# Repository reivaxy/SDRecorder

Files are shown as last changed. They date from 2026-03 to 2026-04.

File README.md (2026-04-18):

# SDRecorder

*About 90% of the code and this README was written by Claude Haiku 4.5 through GitHub Copilot in VSC, with minimal editing.*

A compact ESP32-based audio recording device with SD card storage, WiFi web interface, and power-efficient operation for portable recording applications.

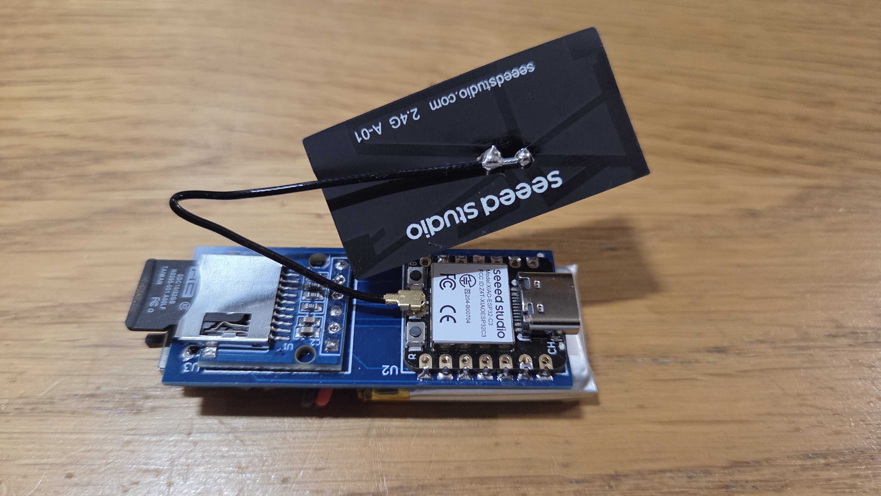
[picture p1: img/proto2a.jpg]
 
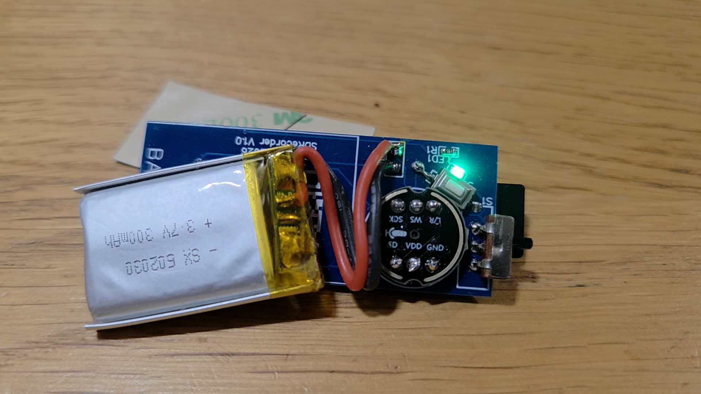
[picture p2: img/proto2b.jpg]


Here is version 2 with its case:

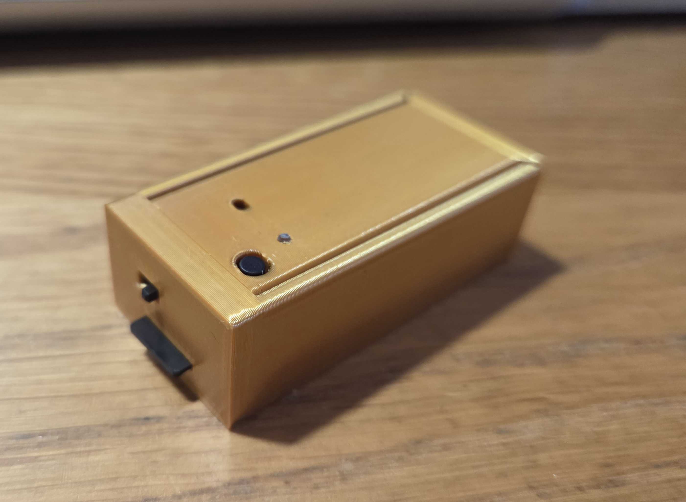
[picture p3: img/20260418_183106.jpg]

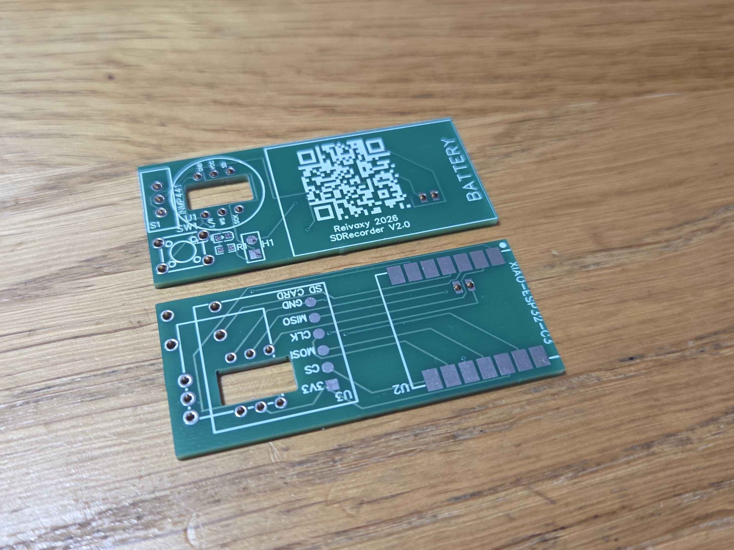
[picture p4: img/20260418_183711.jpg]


Check this recorded sample:

[rec004.wav](https://github.com/user-attachments/files/26235473/rec004.wav)

## Overview

SDRecorder is a battery-powered audio recorder that captures WAV files to an SD card. The device features a simple push-button interface for recording control, an LED status indicator, and a web-based interface for settings management and file access. The design prioritizes low power consumption through intelligent sleep modes.

## Features

- **Audio Recording**: Captures audio to SD card in WAV format
- **Automatic File Rotation**: Creates new recording files at configurable intervals to optimize storage and prevent extremely large files
- **Web-Based Interface**: Access settings, view recordings, and manage files through a WiFi access point
- **Power Efficiency**: ESP32 enters light sleep mode when idle to extend battery life
- **Simple Controls**: One push button for all operations
- **Status Indicator**: LED provides visual feedback for device status
- **File Management**: Download and delete recordings directly from the web interface
- **Flexible Settings**: Configure recording intervals, WiFi credentials, sleep timing, and more

## Push Button Usage

The single push button provides three levels of interaction:

### Quick Press (< 2 seconds)
- **First press**: Start recording
- **Second press**: Stop recording
- The device immediately begins capturing audio to the SD card when recording starts

### Long Press (2+ seconds)
- **Hold for 2 seconds but less than 6**: Start the WiFi access point
- Once activated, the device creates a WiFi network you can connect to
- Default SSID and password can be configured via the web interface at http://192.168.1.4

### Very long press (6+ seconds)
- reset the ESP32

### Power Management
- When not in use, the device automatically enters light sleep mode after a configurable delay
- Pressing the button wakes the device from sleep
- This design significantly reduces battery consumption during idle periods

## LED Status Indicators

- **Slow Flash** (every 2 seconds while recording): Device is recording audio
- **Quick Flash** (continuous): SD card error - either the card is absent or cannot be written to
- **Double Blink** (on startup): System ready and waiting for input
- **Triple Blink**: Wifi Access Point and web server started or stopped

## WiFi Web Interface

When the WiFi access point is active, connect to the network and navigate to `http://192.168.1.4` to access the web interface.

### Available Pages

#### Home Page (`/`)
Main dashboard for recording control and quick status overview
- Display current recording status
- Start/stop recording controls
- Quick access to settings and file management

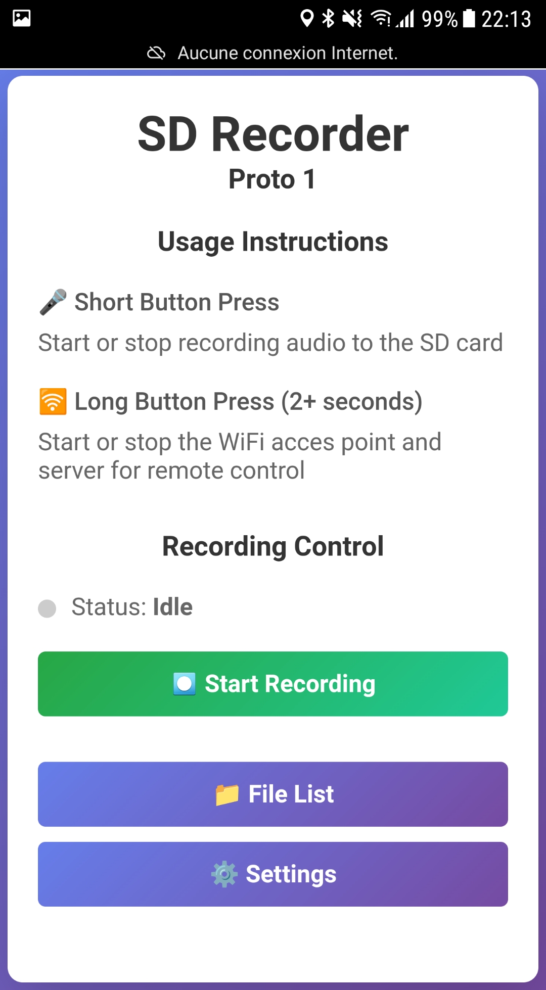
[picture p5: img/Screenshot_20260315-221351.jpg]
Home Page


After pressing the "Start Recording" button:

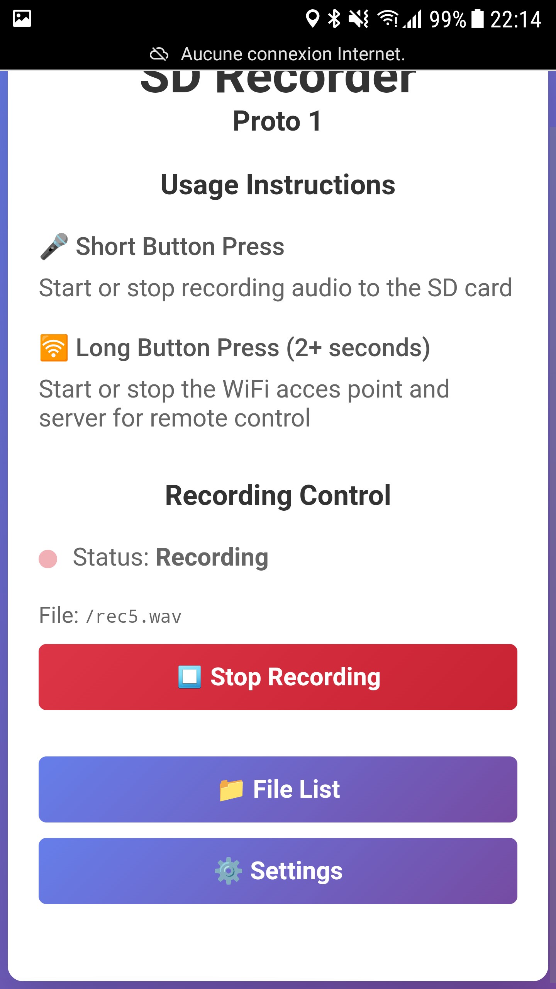
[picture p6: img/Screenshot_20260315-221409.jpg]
While recording


#### Settings Page (`/settings`)
Configure device behavior and preferences:
- **File Split Interval**: Set how many seconds of recording before a new file is created
- **WiFi Credentials**: Configure the AP SSID and password
- **Sleep Timer**: Adjust the delay before the device enters sleep mode
- **Server Auto-Start**: Enable/disable WiFi server startup after device restart
- Save and apply changes to persistent storage

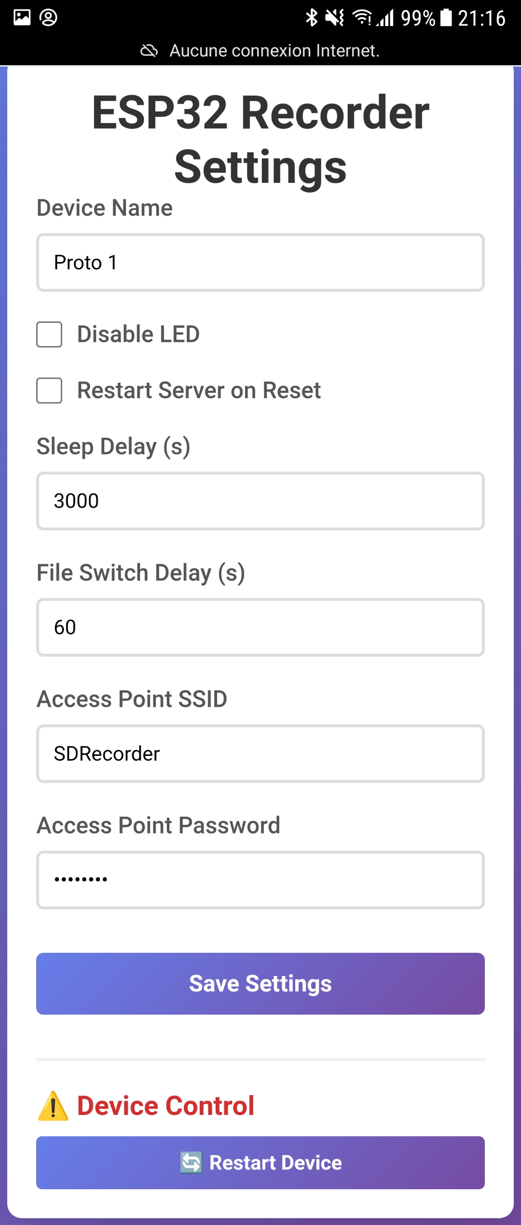
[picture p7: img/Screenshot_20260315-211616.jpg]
Settings Page


#### Files Page (`/files`)
Manage recorded audio files:
- View list of all recordings on the SD card with file sizes and date
- Download files directly to your mobile phone or computer
- Delete individual files or manage storage space

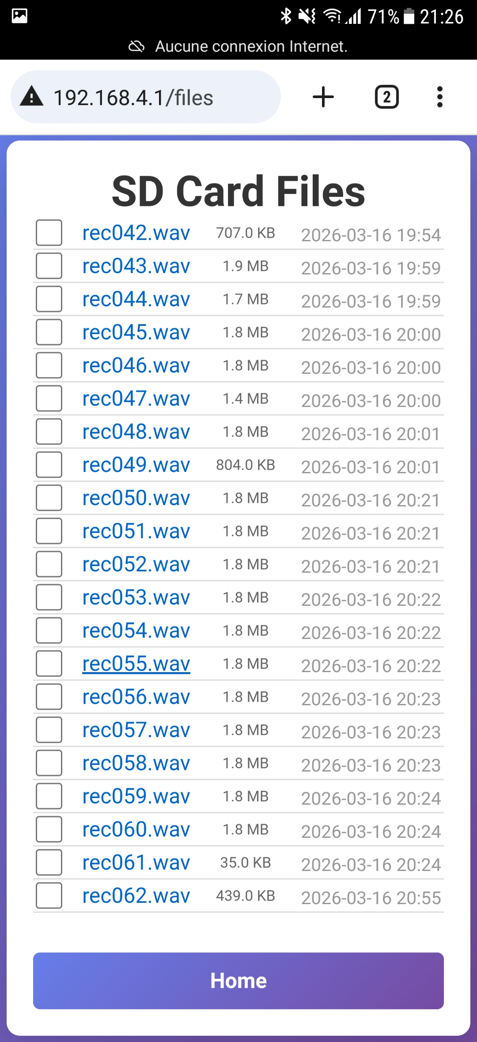
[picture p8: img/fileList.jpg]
Files Page


### API Endpoints (for advanced users)

- `GET /apis/settings` - Retrieve current settings in JSON format
- `POST /apis/settings` - Update settings
- `POST /apis/recording/start` - Start recording
- `POST /apis/recording/stop` - Stop recording
- `GET /apis/recording/status` - Get current recording status
- `POST /apis/files/delete` - Delete files
- `POST /apis/system/restart` - Restart the device
- `POST /apis/system/time` - Set the device time (accepts timestamp in JSON body)
- `GET /apis/system/time` - Get the current device time and RTC status

### Tools

A python script opens a UI allowing to select a source folder containing .wav files and stich them into one single .wav file.
This is handy in case you use the automatic file switching feature. 
Check the firmware/pc folder in this repository.

## Hardware Prototype

Here is the early breadboard prototype.



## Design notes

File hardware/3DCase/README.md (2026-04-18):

# Case

Both parts should be printed vertically.

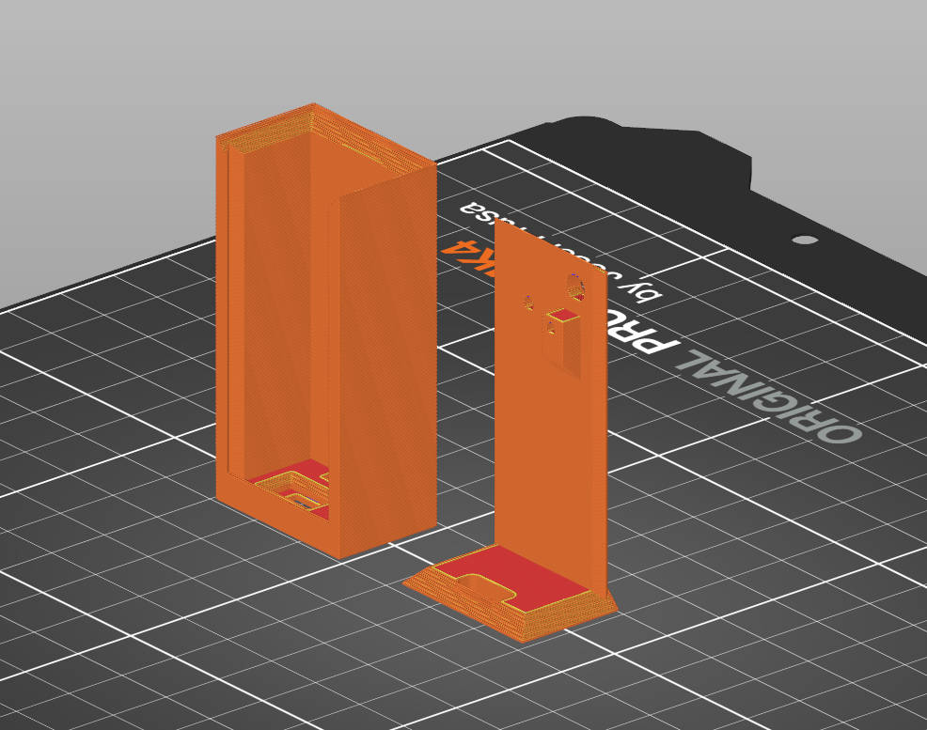
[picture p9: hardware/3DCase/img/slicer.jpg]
Slicer view
 

Assemble flat: put the bottom part on a table, then insert the USB-C in its slot while making sure the push button is going through the hole.

Then slide the top case close slowly, making sure the antenna is not squeezed at the USB extremity.

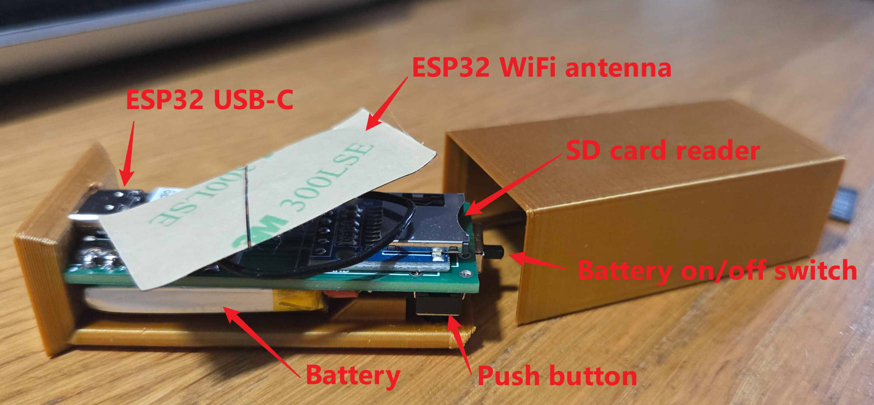
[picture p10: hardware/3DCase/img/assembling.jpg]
 

Push a little bit of optical fiber down the led hole (about 5mm should do).

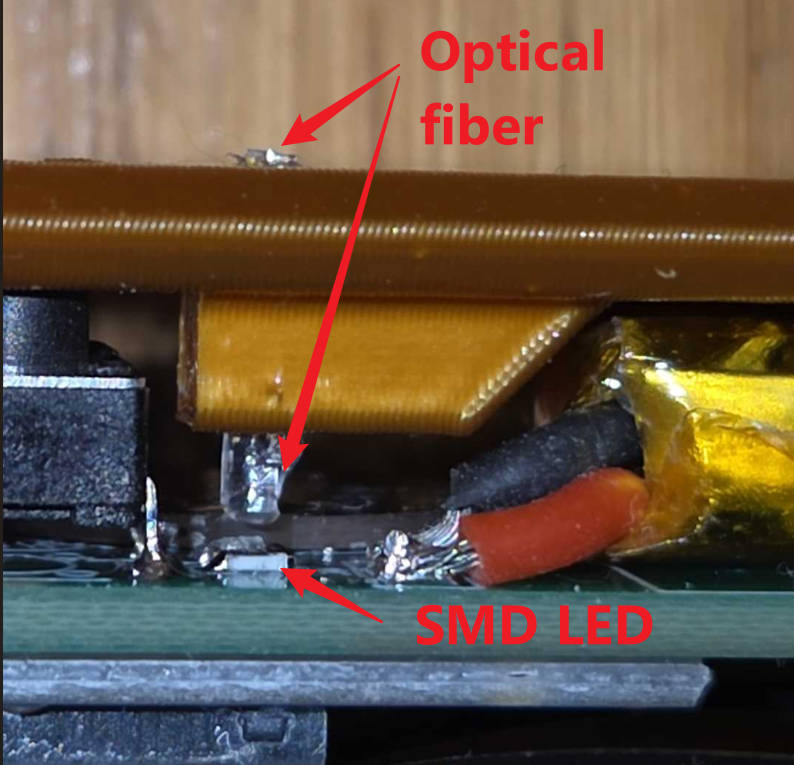
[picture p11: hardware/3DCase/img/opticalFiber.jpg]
 

And enjoy.

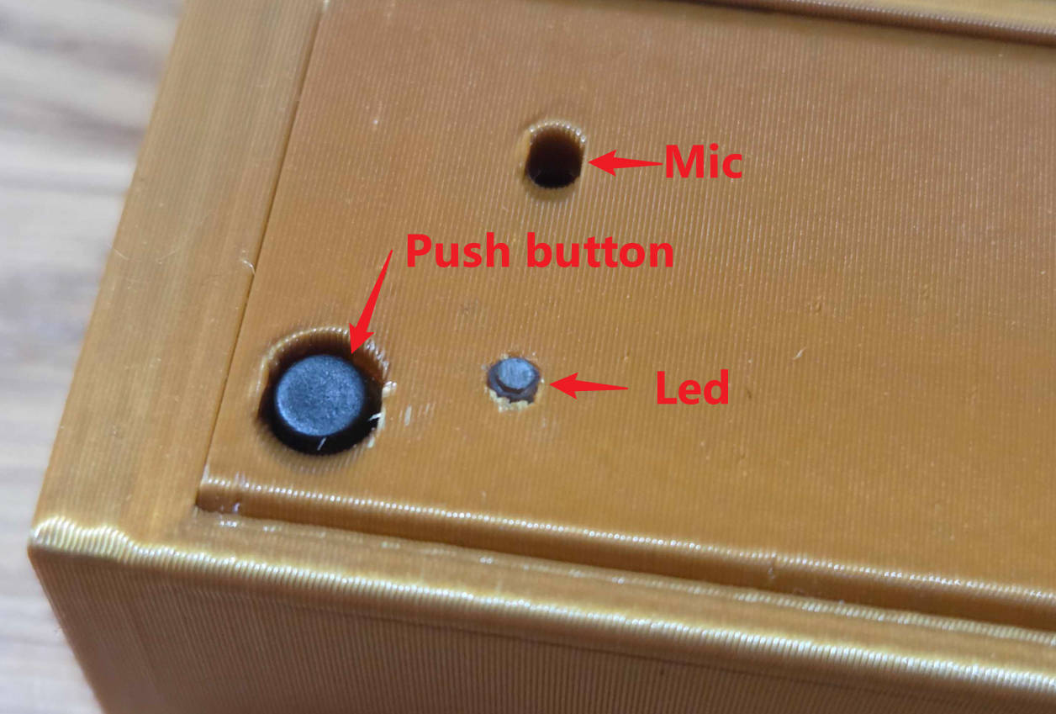
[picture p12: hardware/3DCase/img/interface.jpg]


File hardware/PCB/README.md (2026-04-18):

# PCB Manufacturing

This PCB can be easily manufactured and ordered through online PCB services such as JLCPCB, PCBWay, or similar providers.

Version 1 is a bit buggy but can work.

The push button print is not right for the push button I had in stock, and the microphone board needs to be mounted on pins. Next version should take care of this and maybe accomodate several push buttons sizes.

## How to Order

Simply upload the Gerber files to your chosen PCB manufacturer's website. The Gerber files contain all the necessary information for fabrication including traces, layers, holes, and other manufacturing specifications.

## Assembly

Three tricky parts:
- the battery pads underneath the ESP32: Put the ESP32 in place and make sure it does not move, then from the other side of the PCB heat the holes joining the pads and put solder. It worked for me. Alternatively, use solder paste and hot air, but I didn't try it yet.
- the SD board: soldered without pins, just heat the holes and put solder from the top, capilarity will do the rest.
- the microphone board: will be similar in the next pcb version, for now mount it on pins but the pins should not emerge on the other side of the pcb since the battery rests agains the pcb.

## Schematics

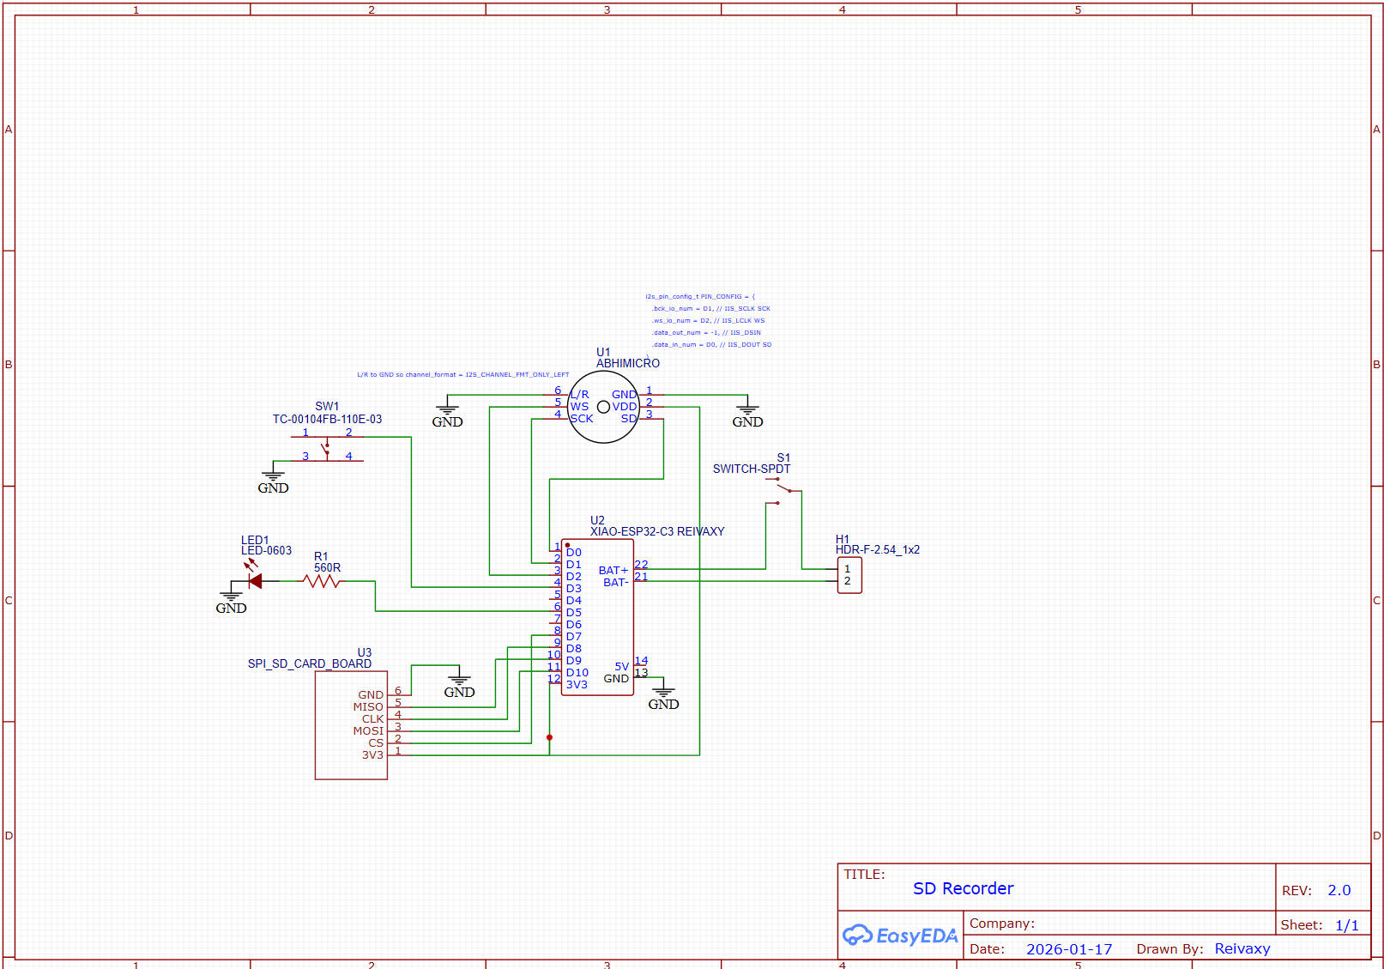
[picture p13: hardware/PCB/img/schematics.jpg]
Schematics


## PCB Views

Dimensions: 51.9 mm* 21.7 mm

Top side

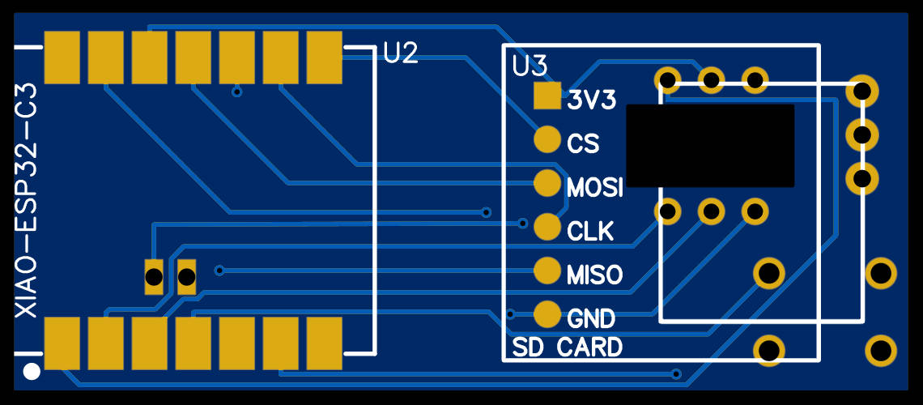
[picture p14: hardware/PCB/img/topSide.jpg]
Top Side


Bottom side

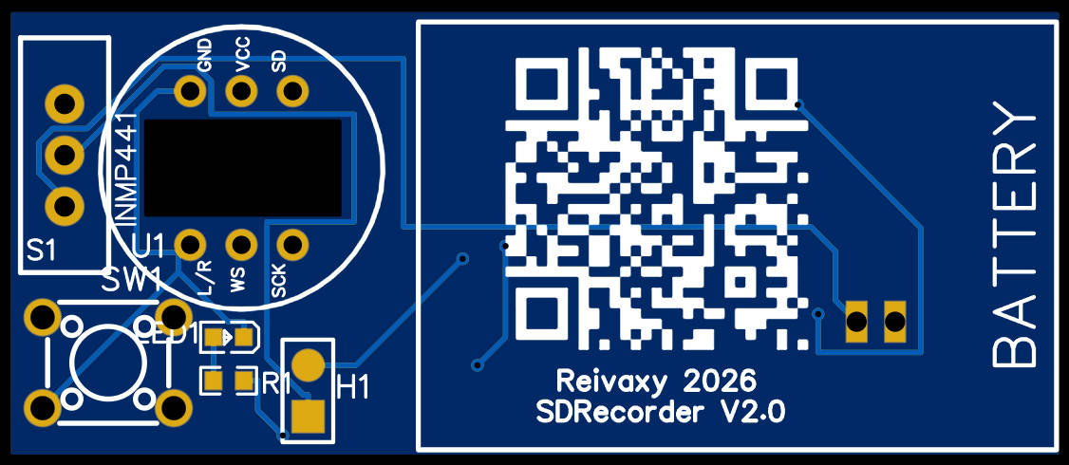
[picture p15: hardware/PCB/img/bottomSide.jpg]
Bottom Side


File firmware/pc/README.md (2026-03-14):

# .wav file merger

The mergeWav.py is a 100% AI generated unedited python script you can use to merge the .wav files produced by the SDRecorder.

When recording, the SDRecorder switches to a new file every X minutes (1 minute for now, this will be an accessible parameter through wifi soon-ish), so that not much recording is lost when the battery charge is too low to power the device.

You may need to install the PyQt6 package:

`> pip install PyQt6`

Then run the script:

`> python mergeWav.py`

This python script with a simple GUI allows to stitch them easily.

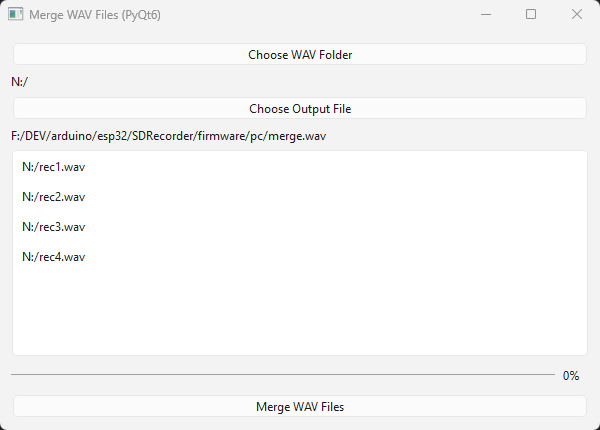
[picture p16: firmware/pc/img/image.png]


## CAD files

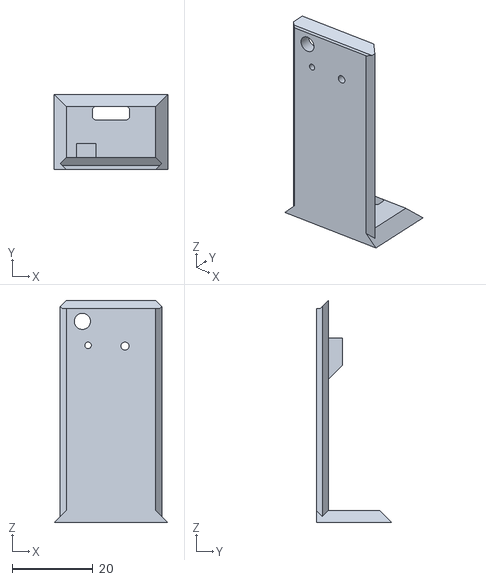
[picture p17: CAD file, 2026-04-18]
hardware/3DCase/bottom.stl
28.2 x 18.7 x 55.1

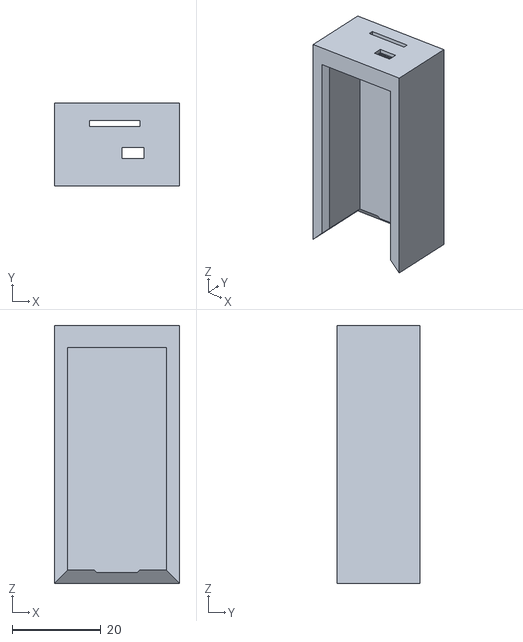
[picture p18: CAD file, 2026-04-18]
hardware/3DCase/top.stl
28.2 x 18.7 x 58.1

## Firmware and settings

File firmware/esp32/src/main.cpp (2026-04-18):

#include "main.h"
#include "recorderServer.h"
#include "recorderPreferences.h"
#include "rtc.h"

#define I2S_BCK_PIN D1
#define I2S_WS_PIN D2
#define I2S_SD_PIN D0

#define SD_CS_PIN D7
#define SD_MOSI_PIN MOSI
#define SD_MISO_PIN MISO
#define SD_SCK_PIN SCK

#define BUTTON_PIN D3
#define LED_PIN D5

#define I2S_NUM I2S_NUM_0

bool isRecording = false;
unsigned long lastBlinkTime = 0;

time_t lastFileSwitch = 0;
time_t lastActivation = 0;
bool sdPresent = false;

Led led(LED_PIN);
BlinkMode slowMode(40, 2000, 0);      // 100ms on, 2s off, infinite
BlinkMode fastMode(100, 100, 0);       // 100ms on/off, infinite
BlinkMode twiceMode(400, 400, 2);      // 400ms on/off, 2 blinks max
BlinkMode threeTimesMode(100, 100, 3);    // 200ms on/off, 3 blinks max
SDCard sdCard(SD_CS_PIN, SD_SCK_PIN, SD_MISO_PIN, SD_MOSI_PIN);
Button button(BUTTON_PIN);
RecorderPreferences* preferences = nullptr;
RecorderServer* recorderServer = nullptr;
RTC* rtc = nullptr;
 
const i2s_config_t i2s_config = {
  .mode = (i2s_mode_t)(I2S_MODE_MASTER | I2S_MODE_RX | I2S_MODE_TX),
  .sample_rate = SAMPLE_RATE,
  .bits_per_sample = I2S_BITS_PER_SAMPLE_32BIT,  
  .channel_format = I2S_CHANNEL_FMT_ONLY_LEFT,
  .communication_format = I2S_COMM_FORMAT_STAND_I2S,
  .intr_alloc_flags = ESP_INTR_FLAG_LEVEL1,
  .dma_buf_count = 8,
  .dma_buf_len = 1024,
  .use_apll = false,
  .tx_desc_auto_clear = false,
  .fixed_mclk = 0
};

const i2s_pin_config_t pin_config = {
  .bck_io_num = I2S_BCK_PIN,
  .ws_io_num = I2S_WS_PIN,
  .data_out_num = I2S_PIN_NO_CHANGE,
  .data_in_num = I2S_SD_PIN
};

// Forward declarations
void startRecording();
void stopRecording();

void setup() {
  Serial.begin(115200);
  delay(3000); // Allow time for Serial to initialize
  // Make sure wifi is off to save power and avoid SD card interference
  WiFi.mode(WIFI_OFF);
  // Turn off Bluetooth as well to save power and avoid interference
  btStop();
  
  // Initialize preferences
  preferences = new RecorderPreferences();
  
  // Pass preferences to LED
  led.setPreferences(preferences);

  // Initialize RTC
  rtc = new RTC();
  log_i("RTC initialized (waiting for time synchronization)");

  // Initialize SDCard with preferences and RTC
  if (!sdCard.begin(preferences, rtc)) {
    log_e("SD Card initialization failed");
    sdPresent = false;
    led.setMode(fastMode);
  } else {
    sdPresent = true;
    Serial.println("SD Card Ready.");
    i2s_driver_install(I2S_NUM, &i2s_config, 0, NULL);
    i2s_set_pin(I2S_NUM, &pin_config);
    i2s_zero_dma_buffer(I2S_NUM);
    log_i("System ready. Click button to start recording.");
    led.setMode(twiceMode);
    lastActivation = millis();
  }
  
  // Initialize RecorderServer with RTC
  recorderServer = new RecorderServer(preferences, &sdCard, rtc);
  recorderServer->setRecordingCallbacks(
    []() { startRecording(); },
    []() { stopRecording(); },
    []() -> bool { return isRecording; }
  );
  
  // Check if server should auto-start after restart
  if (preferences->getSettingBool(PREF_RESTART_SERVER)) {
    log_i("Auto-starting server after restart");
    recorderServer->start();
    led.setMode(threeTimesMode);
    preferences->setSetting(PREF_RESTART_SERVER, false);  // Reset the flag
  }
}

void startRecording() { 
  log_i("Starting recording.");
  lastFileSwitch = millis();
  if (!sdCard.initNewFile()) {
    led.setMode(fastMode);
    log_e("Starting recording failed.");
    return;
  }
  isRecording = true;
  led.setMode(slowMode);
  log_i("Recording started.");
}

void stopRecording() {
  log_i("Stopping recording.");
  sdCard.closeCurrentFile();
  isRecording = false;
  led.off();
  log_i("Recording stopped.");
}

void loop() {  
  button.run();
  led.run();
  recorderServer->run();
  
 
  if (!sdPresent) {
    return;
  }  

  // when not recording for a while, enter light sleep mode to save power.
  // Keep delay long enough, sleep messes up the Serial connection 
  // and prevents uploading new code even after reset, until the next unplug/plug.
  int sleepDelay = preferences->getSettingInt(PREF_SLEEP_DELAY_S) * 1000;
  if (millis() - lastActivation > sleepDelay && !recorderServer->isRunning()) {
    log_i("No activity, going to light sleep...");
    fflush(stdout);
    gpio_wakeup_enable(GPIO_NUM_5, GPIO_INTR_LOW_LEVEL);
    esp_sleep_enable_gpio_wakeup();
    esp_light_sleep_start();
    // Beware, after this, USB Serial no longer works (logs, upload, ...) 
    // until the next time it is unplugged / plugged in.
    lastActivation = millis();

    // This does not work :( 
    // vTaskDelay(pdMS_TO_TICKS(10));
    // periph_module_reset(PERIPH_USB_DEVICE_MODULE);
    // vTaskDelay(pdMS_TO_TICKS(10));
    // Serial.begin(115200);
    // delay(3000);
    // printf("Woke up from light sleep!\n");
    // fflush(stdout);
  }
  
  ButtonState buttonState = button.readState();
  if (buttonState == ButtonState::SHORT_PRESS) {
    if (isRecording) {
      stopRecording();
    } else {
      startRecording();
    }
  } else if (buttonState == ButtonState::LONG_PRESS) {
    if (recorderServer->isRunning()) {
      led.setMode(threeTimesMode);
      recorderServer->stop();
      log_i("Web server stopped.");
      if (isRecording) {
        led.setMode(slowMode);
      }
    } else {
      led.setMode(threeTimesMode);
      recorderServer->start();
      log_i("Web server started.");
    }
    lastActivation = millis();
  } else if (buttonState == ButtonState::VERY_LONG_PRESS) {
    log_i("Button held for 6+ seconds. Resetting ESP32...");
    delay(500);
    ESP.restart();
  }
  

  if (isRecording) { 
    size_t bytesRead;
    int32_t i2sBuffer[256]; 
    lastActivation = millis();
    
    i2s_read(I2S_NUM, (void *)i2sBuffer, sizeof(i2sBuffer), &bytesRead, portMAX_DELAY);
    
    int16_t samples16[256];
    int samplesCount = bytesRead / 4;
    
    for (int i = 0; i < samplesCount; i++) {
      samples16[i] = (int16_t)(i2sBuffer[i] >> 14);
    }
    
    sdCard.write((uint8_t *)samples16, samplesCount * 2);

    // New file every X seconds.
    int fileSwitchDelay = preferences->getSettingInt(PREF_FILE_SWITCH_DELAY_S) * 1000;
    if (millis() - lastFileSwitch > (unsigned long)fileSwitchDelay) { 
      Serial.print("Switching recording file.");
      stopRecording();
      startRecording();
    }
  }
}

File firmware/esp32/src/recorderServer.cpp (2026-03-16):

#include "recorderServer.h"
#include "styles.h"
#include "modalStyle.h"
#include "filesStyle.h"
#include "settingsHtmlPage.h"
#include "homeHtmlPage.h"
#include "filesHtmlPage.h"
#include <SD.h>

RecorderServer::RecorderServer(RecorderPreferences* preferences, SDCard* sdCard, RTC* rtc)
    : server(80), preferences(preferences), sdCard(sdCard), rtc(rtc), running(false),
      onStartRecording(nullptr), onStopRecording(nullptr), getIsRecording(nullptr) {
}

RecorderServer::~RecorderServer() {
    stop();
}

void RecorderServer::start() {
    if (running) {
        log_w("Server is already running");
        return;
    }
    
    // Set WiFi mode to Access Point
    WiFi.mode(WIFI_AP);
    
    // Configure AP with default credentials
    String ssid = preferences->getSettingString(PREF_AP_SSID);
    String password = preferences->getSettingString(PREF_AP_PASSWORD);
    log_i("Starting AP with SSID: %s", ssid.c_str());
    
    if (!WiFi.softAP(ssid, password)) {
        log_e("Failed to start AP");
        return;
    }
    
    log_i("AP started: %s", ssid.c_str());
    log_i("IP address: %s", WiFi.softAPIP().toString().c_str());
    
    // Register request handlers
    server.on("/", HTTP_GET, [this]() { handleRoot(); });
    server.on("/settings", HTTP_GET, [this]() { handleSettings(); });
    server.on("/files", HTTP_GET, [this]() { getFilesHtmlPage(); });
    server.on("/download", HTTP_GET, [this]() { handleDownload(); });
    server.on("/apis/settings", HTTP_GET, [this]() { handleGetSettingsApi(); });
    server.on("/apis/settings", HTTP_POST, [this]() { handlePostSettingsApi(); });
    server.on("/apis/recording/start",  HTTP_POST, [this]() { handleStartRecordingApi(); });
    server.on("/apis/recording/stop",   HTTP_POST, [this]() { handleStopRecordingApi(); });
    server.on("/apis/recording/status", HTTP_GET,  [this]() { handleGetRecordingStatusApi(); });
    server.on("/apis/files/delete",     HTTP_POST, [this]() { handleDeleteFilesApi(); });
    server.on("/apis/system/restart",   HTTP_POST, [this]() { handleRestartApi(); });
    server.on("/apis/system/time",      HTTP_POST, [this]() { handleSetTimeApi(); });
    server.on("/apis/system/time",      HTTP_GET,  [this]() { handleGetTimeApi(); });
    server.onNotFound([this]() { handleNotFound(); });
    
    // Start server
    server.begin();
    running = true;
    
    log_i("RecorderServer started on port 80");
}

void RecorderServer::stop() {
    if (!running) {
        return;
    }
    
    server.stop();
    WiFi.softAPdisconnect(true);
    WiFi.mode(WIFI_OFF);
    running = false;
    
    log_i("RecorderServer stopped");
}

void RecorderServer::run() {
    if (running) {
        server.handleClient();
    }
}

void RecorderServer::handleRoot() {
    log_i("Handling root request");
    server.send(200, "text/html", getHomeHtmlPage());
}

void RecorderServer::handleSettings() {
    log_i("Handling root request");
    server.send(200, "text/html", getSettingsHtmlPage());
}

void RecorderServer::handleGetSettingsApi() {
    server.send(200, "application/json", getSettingsJson());
}

void RecorderServer::handlePostSettingsApi() {
    if (!server.hasArg("plain")) {
        server.send(400, "application/json", "{\"error\":\"No content\"}");
        return;
    }
    
    String json = server.arg("plain");
    log_i("Settings payload received: %s", json.c_str());
    setSettingsFromJson(json);
    
    server.send(200, "application/json", "{\"status\":\"success\"}");
}

void RecorderServer::handleNotFound() {
    server.send(404, "application/json", "{\"error\":\"Not Found\"}");
}

void RecorderServer::setRecordingCallbacks(std::function<void()> startCb,
                                            std::function<void()> stopCb,
                                            std::function<bool()> isRecCb) {
    onStartRecording = startCb;
    onStopRecording  = stopCb;
    getIsRecording   = isRecCb;
}

void RecorderServer::handleStartRecordingApi() {
    // Check if RTC needs initialization from browser time
    if (rtc && !rtc->isInitialized() && server.hasArg("plain")) {
        String json = server.arg("plain");
        JsonDocument doc;
        DeserializationError error = deserializeJson(doc, json);
        
        if (!error && !doc["timestamp"].isNull()) {
            time_t timestamp = doc["timestamp"].as<time_t>();
            rtc->setTime(timestamp);
            log_i("RTC initialized from browser time during start recording");
        }
    }
    
    if (!onStartRecording) {
        server.send(501, "application/json", "{\"error\":\"Not implemented\"}");
        return;
    }
    onStartRecording();
    server.send(200, "application/json", "{\"status\":\"recording\"}");
}

void RecorderServer::handleStopRecordingApi() {
    if (!onStopRecording) {
        server.send(501, "application/json", "{\"error\":\"Not implemented\"}");
        return;
    }
    onStopRecording();
    server.send(200, "application/json", "{\"status\":\"idle\"}");
}

void RecorderServer::handleGetRecordingStatusApi() {
    bool recording = getIsRecording ? getIsRecording() : false;
    String fileName = recording ? sdCard->getCurrentFileName() : "";
    
    JsonDocument doc;
    doc["recording"] = recording;
    if (recording && fileName.length() > 0) {
        doc["filename"] = fileName;
    }
    
    String json;
    serializeJson(doc, json);
    server.send(200, "application/json", json);
}

void RecorderServer::handleRestartApi() {
    log_i("Restart API called");
    server.send(200, "application/json", "{\"status\":\"restarting\"}");
    
    // Save state to restart with server running
    if (running) {
        preferences->setSetting(PREF_RESTART_SERVER, true);
        log_i("Saved restart server preference");
    }
    
    // Delay a bit to allow response to be sent
    delay(500);
    
    // Restart the device
    ESP.restart();
}
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

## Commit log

2026-03-08 Adding schematic
2026-03-08 Gerber file
2026-03-14 Add button handling and file read/write functionality
    - Implement Button class for managing button states and debouncing.
    - Add methods to read and write files in SDCard class.
    - Update main loop to utilize button state for recording control.
2026-03-14 Long button press now opens WIFI AP, with settings webpage.
2026-03-15 Implement RecorderPreferences class for managing user settings and refactor LED and RecorderServer to utilize preferences
2026-03-15 Enhance SDRecorder functionality and UI
    - Updated README.md to reflect new features and usage instructions.
    - Modified button.h to include a new button state for very long presses.
    - Added filesStyle.h and modalStyle.h for improved file management and modal dialog styling.
    - Expanded recorderPreferences.h to include new preferences for file switch delay and server restart.
    - Enhanced recorderServer.h and recorderServer.cpp to support new API endpoints for file management and recording control.
    - Implemented file deletion functionality in sdCard.cpp and updated methods for file management.
    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
2026-03-15 Add PCB manufacturing documentation and images
2026-03-16 Add RTC functionality and file index management to ESP32 Recorder
2026-03-20 Update platformio configuration and adjust pin definitions; add prototype images
2026-03-20 Update README for clarity and prototype description
2026-03-20 Update PCB README with version notes and image files
2026-03-25 Add recorded sample link to README
    Added a link to a recorded sample audio file in the README.
2026-04-18 PCB V2: new push button, ledt on D3, hole for lower mic mount
    [bottom.stl, top.stl]
2026-04-18 fixed led hole, added case instructions and pictures
    [bottom.stl]
